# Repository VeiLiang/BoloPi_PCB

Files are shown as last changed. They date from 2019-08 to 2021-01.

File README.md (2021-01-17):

# BoloPi_PCB
----------------------------
注意:板子目前发现的问题:
1. V1-V3版本的板子的R1和R2都是没有改阻值的，默认10K。而F1C100s不能贴10K，需要200K。有可能贴了10K会导致芯片工作不正常！
2. 版本1和版本2的EA3036QDR输入端电源没有加电容，在某些电源纹波大的情况下可能会烧EA3036QDR
----------------------------
Attention: flaws found at present:
1. R1 and R2 in V1 -V3 of boards was 10K by default. But f1c100s can't be 10K, it needs 200K. It is possible that 10K will lead to abnormal operation of the chip!
2. The ea3036qdr input power supply of version 1 and version 2 is not equipped with capacitor, which may burn ea3036qdr in case of large power ripple

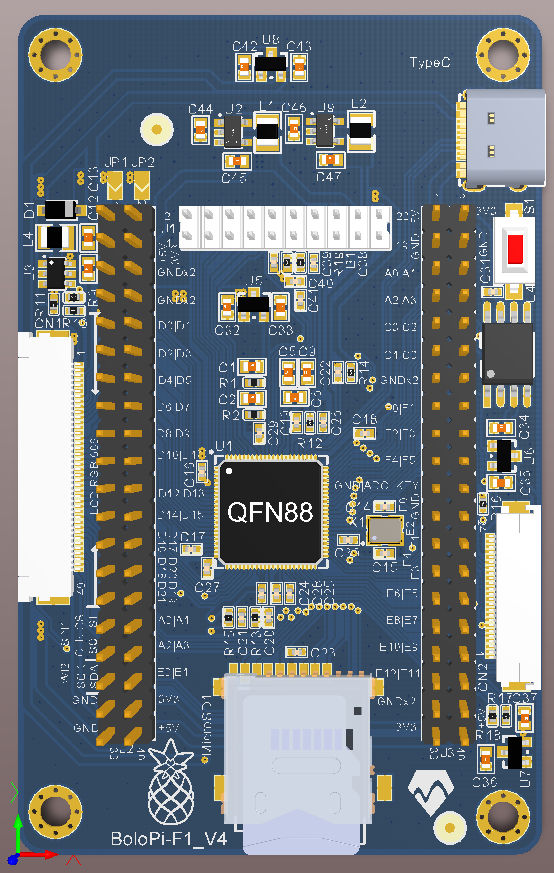
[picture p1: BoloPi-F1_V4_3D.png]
bolopi_F1 3d view

---
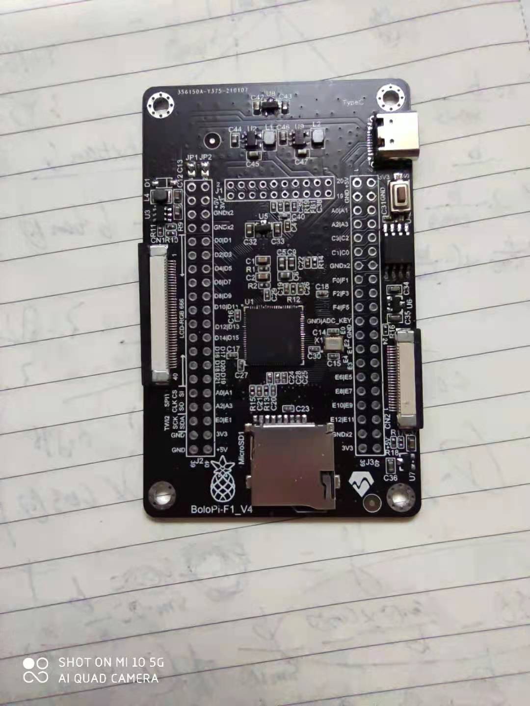
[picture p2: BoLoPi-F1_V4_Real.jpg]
bolopi_F1 in kind

---
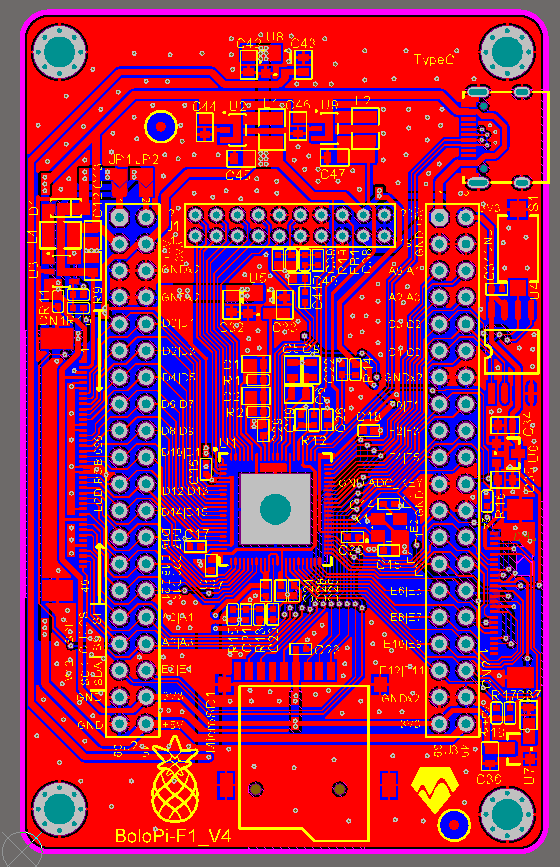
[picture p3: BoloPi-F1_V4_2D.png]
bolopi_F1 2d view

---
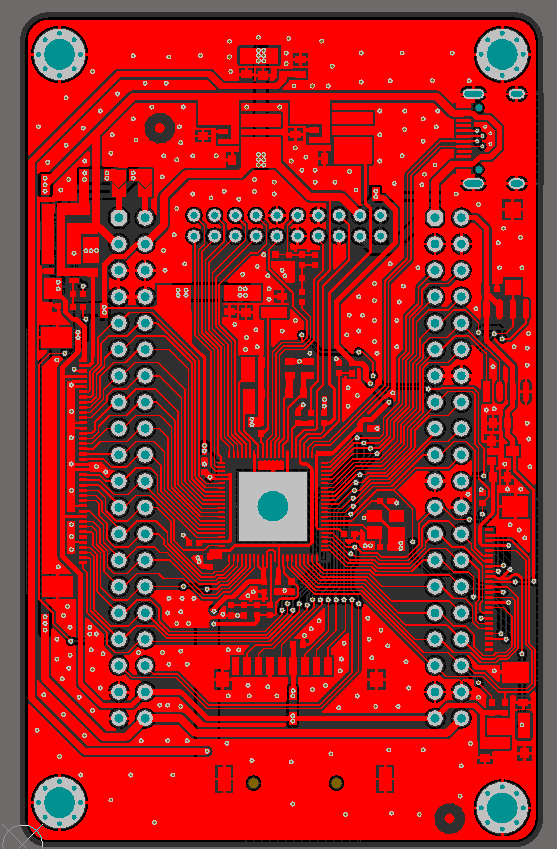
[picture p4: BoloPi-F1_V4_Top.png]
bolopi_F1 top_layer

---
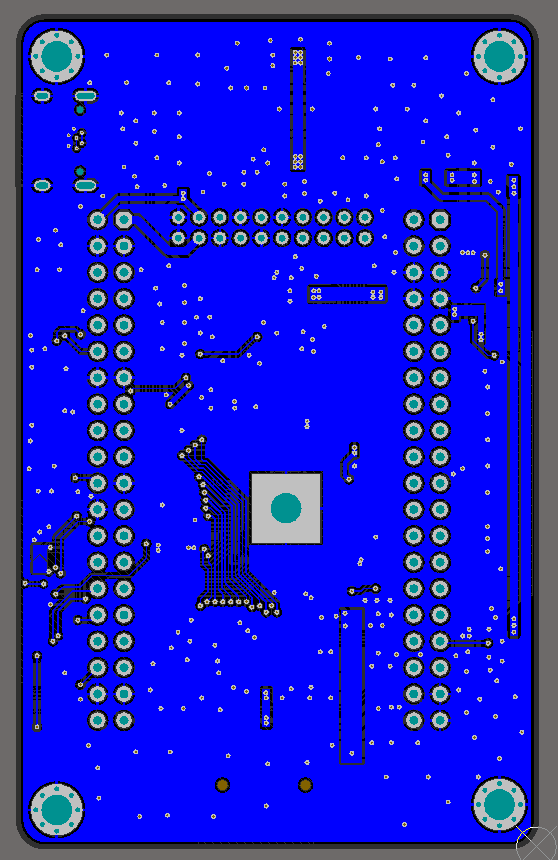
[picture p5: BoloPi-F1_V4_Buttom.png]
bolopi_F1 buttom_layer

---

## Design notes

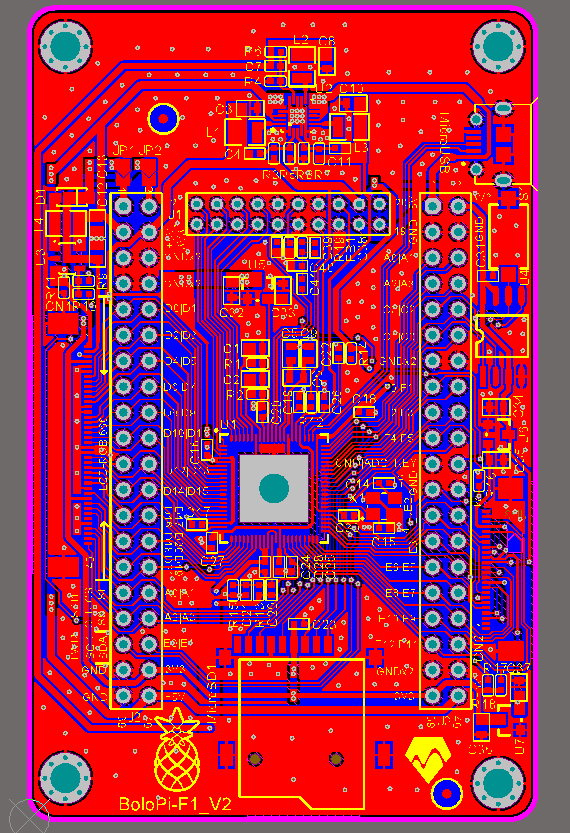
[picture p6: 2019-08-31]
bolopi_F1_V2_0.png

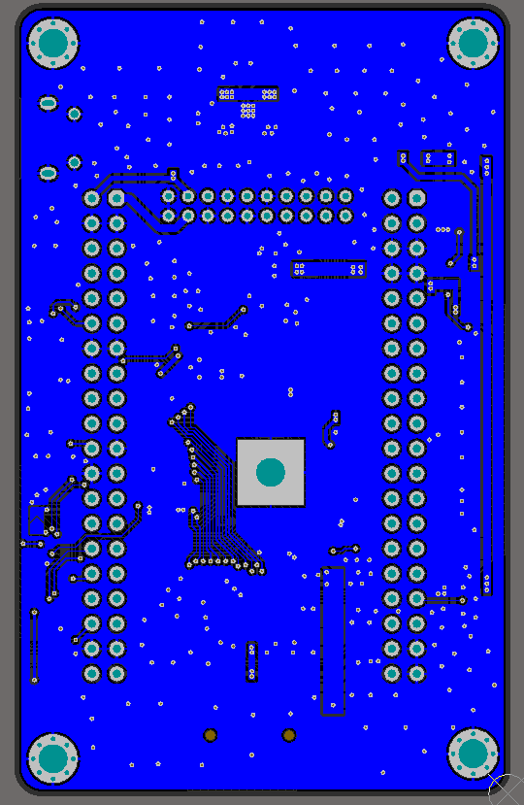
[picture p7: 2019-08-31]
bolopi_F1_V2_1.png

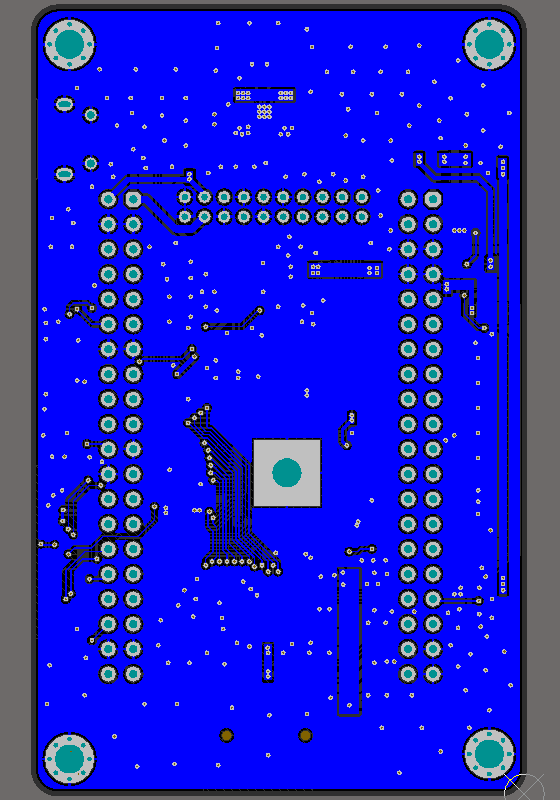
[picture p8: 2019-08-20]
bolopi_F1_1.png

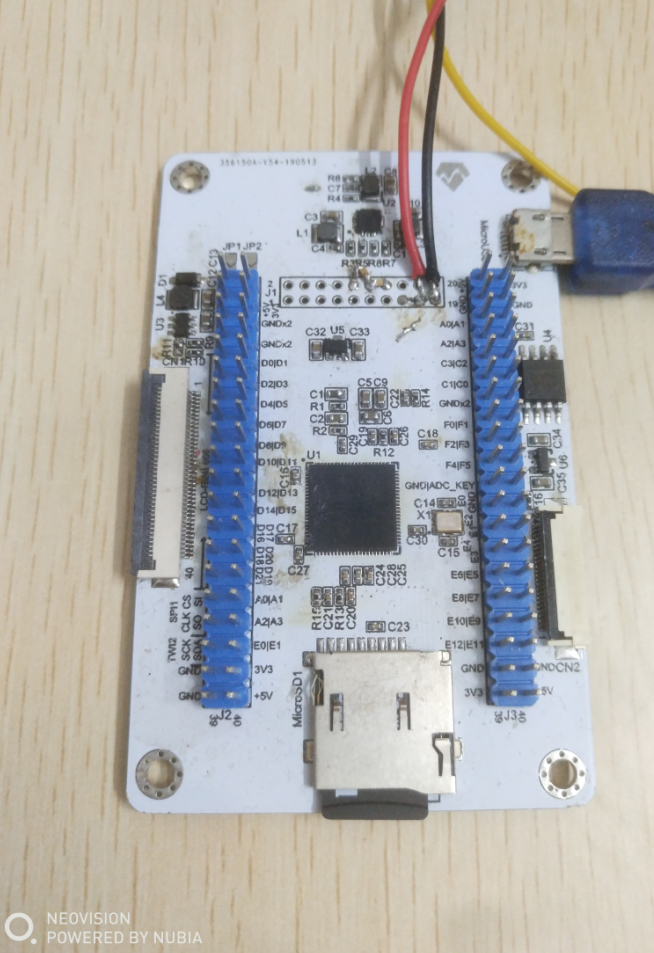
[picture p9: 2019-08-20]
bolopi_F1_3.png

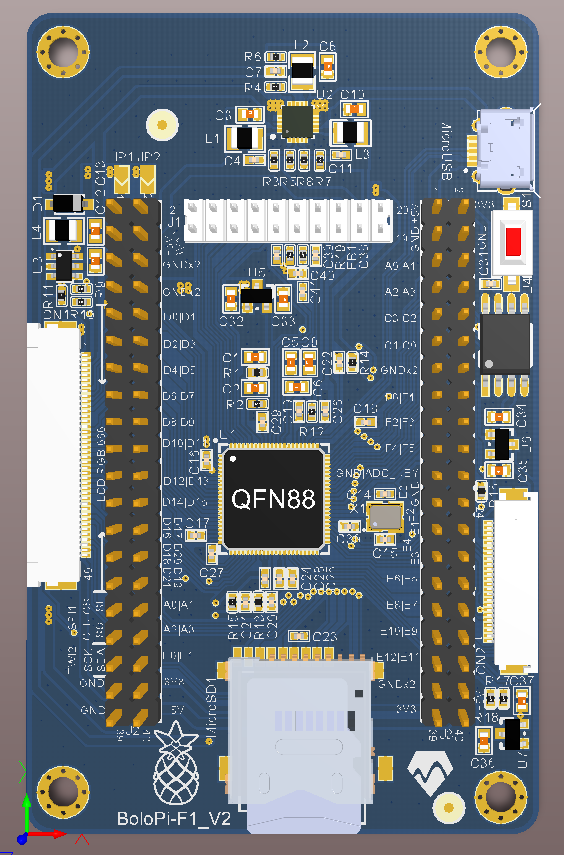
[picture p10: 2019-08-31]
bolopi_F1_V2_2.png

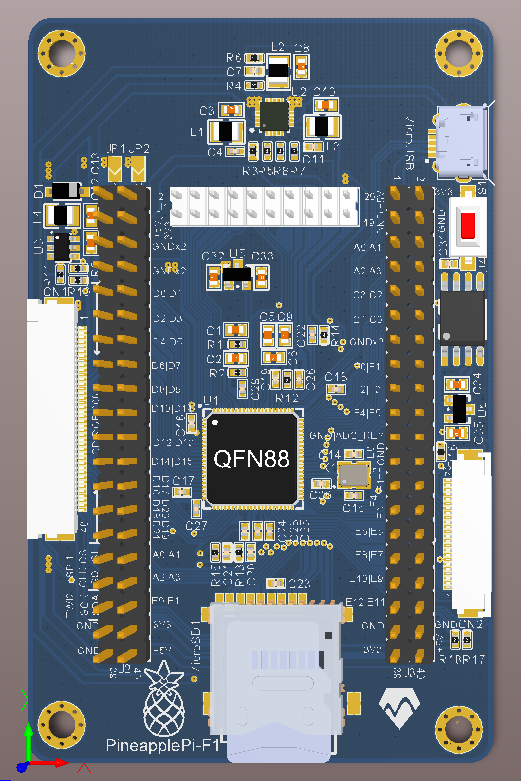
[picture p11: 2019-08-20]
bolopi_F1_2.png

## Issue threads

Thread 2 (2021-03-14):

CSI_MCLK和SDC_D2 为什么可以相连呢

mttbx, 2021-03-14:
如题

VeiLiang, 2021-03-15:
因为MCLK是要时钟输入的，F1C100S没有专门的CLK out，所以选择了PWM作为时钟输出；PWM输出最大频率为24Mhz。

mttbx, 2021-03-15:
谢谢你的回复
SD卡还能正确运行吗？毕竟和它连接在一起了

VeiLiang, 2021-03-15:
> 谢谢你的回复
> SD卡还能正确运行吗？毕竟和它连接在一起了

可以用，不过只能用1bit模式，毕竟io口不够。如果确实SD卡是需要4bit的话，MCLK只能断开，然后用有源晶振了

mttbx, 2021-03-15:
还有个小问题，TP_Y1和PWM0连在一起了，而PWM0是给LED供电电路提供EN的，这样做可以吗，触摸屏不是又要LED供电又要输出坐标吗。

VeiLiang, 2021-03-15:
> 还有个小问题，TP_Y1和PWM0连在一起了，而PWM0是给LED供电电路提供EN的，这样做可以吗，触摸屏不是又要LED供电又要输出坐标吗。

这个也是取舍问题了，一般不用默认的电阻触摸的。所以利用了其中的pwm0来作为背光控制。不能同时用

mttbx, 2021-03-15:
谢谢指点，你的电路给了我启发。

Closed 2021-03-15.

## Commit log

2019-08-20 Add All Files
    Include Pcbdoc and Schdoc
    [PineapplePi-F1.PrjPCB, PineapplePi-F1.SchDoc]
2019-08-31 Update To V2
    1.Add DVDD ldo select use Jump
    2.Add filter whit tvin0
    3.Add mark point in space
    [PineapplePi-F1.PrjPCB, PineapplePi-F1.SchDoc]
2020-05-31 Add V3 Version PCB
    1.Change DC-DC
    2.Change Name to BoloPi
    [BoloPi-F1-V3.PrjPCB, BoloPi-F1-V3.SchDoc]
2021-01-17 Update To V4
    1.Fix Value of VRA1 and VRA2 resistantor value
    2.Delete MicroUSB and add TypeC USB Connector
    3.Add V4 PCB Picture
    [BoloPi-F1-V4.PrjPCB, BoloPi-F1-V4.SchDoc]
